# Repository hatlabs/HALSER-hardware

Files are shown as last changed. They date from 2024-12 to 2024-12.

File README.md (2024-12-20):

# Hat Labs Serial Interface Device (HALSER)

This repository contains the Hat Labs Serial Interface Device (HALSER) hardware design. HALSER is a powerful microcontroller development board designed for marine environments that allows interfacing with legacy NMEA 0183, RS-232 and UART devices.

Since the board has native WiFi and NMEA 2000 compatible CAN bus connectivity, it can be used to create boards with either Signal K or native NMEA 2000 connectivity (or both!).

## Features

The main design features include:

- Built around ESP32-C3, a powerful 32-bit microcontroller with 4 MB of flash
- Wide-range 5-32 V power input with surge protection
- NMEA 2000 compatible CAN interface (4-pin pluggable terminal block screw connector)
- One transmitting and one receiving RS-485 interface for bidirectional communication with NMEA 0183 devices (3-pin pluggable terminal block screw connectors)
- One RS-232 interface for communication with legacy devices (3-pin pluggable terminal block screw connector)
- One UART interface for general-purpose communication (3-pin pluggable terminal block screw connector). UART is 5V tolerant and the output voltage can be set to 3.3V or 5V with a jumper.
- 1-Wire interface (3-pin 2.54 mm header)
- I2C interface with a 4-pin 2.54 mm header
- USB type C interface for programming and serial communication
- All above interfaces with proper electromagnetic compatibilty (EMC) design -- the device won't interfere with navigational devices or radio equipment
- All available general-purpose input/output (GPIO) pins broken out to a separate header
- Board designed to fit low-cost waterproof 100x68x50 mm enclosures

Rendering of a version 1.0.0 board:

<!--
Front side.
![Rev. 1.0.0 board](images/pcb_rev_2.0.0.jpg)

Back side.
![Rev. 1.0.0 board bottom side](images/pcb_rev_2.0.0-back.jpg)

-->

## Getting HALSER

HALSER will be available for purchase at the [Hat Labs web store](https://shop.hatlabs.fi/).

## Documentation

HALSER documentation will be available at the [project GitHub Pages](https://docs.hatlabs.fi/halser/).

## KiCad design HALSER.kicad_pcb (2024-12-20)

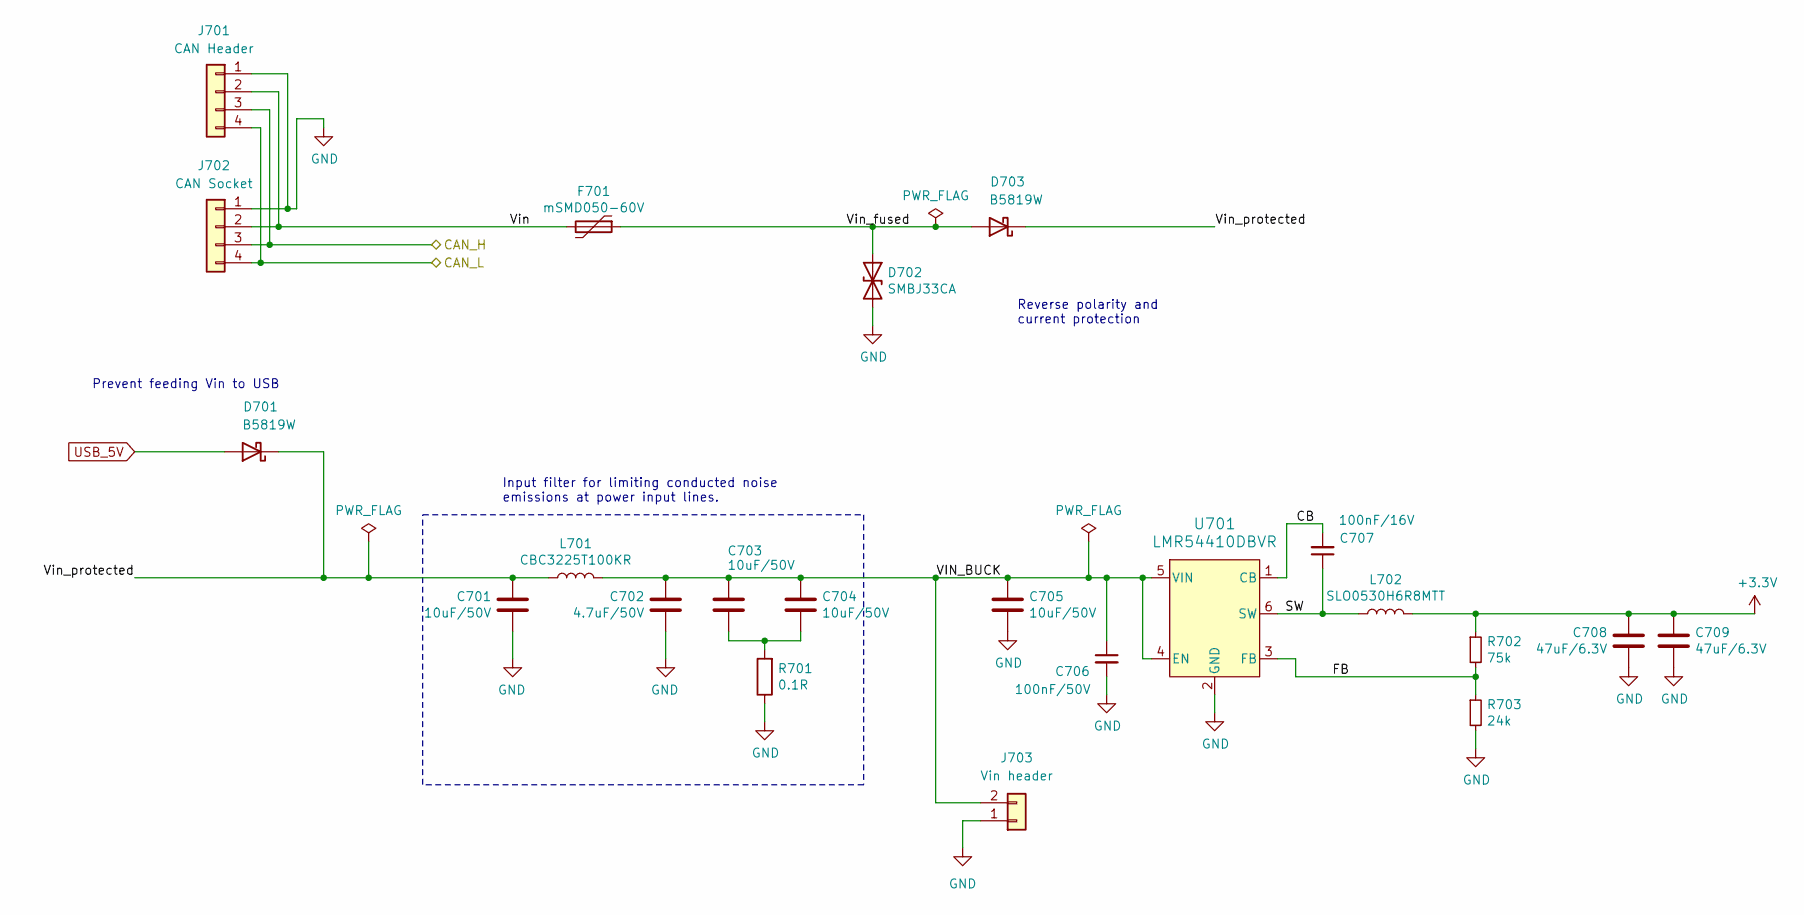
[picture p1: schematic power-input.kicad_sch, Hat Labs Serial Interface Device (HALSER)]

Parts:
C701, C703, C704, C705: 10uF/50V; C_1206_3216Metric; LCSC C13585
C702: 4.7uF/50V; C_0805_2012Metric; LCSC C1710
C706: 100nF/50V; C_0603_1608Metric; LCSC C14663
C707: 100nF/16V; C_0402_1005Metric; LCSC C1525
C708, C709: 47uF/6.3V; C_0805_2012Metric; LCSC C16780
D701, D703: B5819W; D_SOD-123; LCSC C8598
D702: SMBJ33CA; D_SMB; LCSC C114000
F701: mSMD050-60V; Fuse_1812_4532Metric; LCSC C70113
J701: CAN Header; PinHeader_1x04_P2.54mm_Vertical; LCSC C7430360
J702: CAN Socket; PhoenixContact_MCV_1,5_4-G-3.81_1x04_P3.81mm_Vertical; LCSC C8410
J703: Vin header; PinHeader_1x02_P2.54mm_Vertical; LCSC C492401
L701: CBC3225T100KR; L_1210_3225Metric; LCSC C90321
L702: SLO0530H6R8MTT; L_Chilisin_BMRA00050530; LCSC C325965
R701: 0.1R; R_0603_1608Metric; LCSC C3013345
R702: 75k; R_0402_1005Metric; LCSC C208939
R703: 24k; R_0402_1005Metric; LCSC C25769
U701: LMR54410DBVR; SOT-23-6; LCSC C3200265

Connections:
+3.3V: C708.1, C709.1, L702.2, R702.1; also elsewhere on the board
/CAN_H: J701.3, J702.3; also elsewhere on the board
/CAN_L: J701.4, J702.4; also elsewhere on the board
/Power input/CB: C707.2, U701.1 (CB)
/Power input/FB: R702.2, R703.1, U701.3 (FB)
/Power input/SW: C707.1, L702.1, U701.6 (SW)
/Power input/VIN_BUCK: C702.2, C703.1, C704.1, C705.1, C706.1, J703.2, L701.2, U701.4 (EN), U701.5 (VIN)
/Power input/Vin: F701.2, J701.2, J702.2
/Power input/Vin_fused: D702.1 (A1), D703.2 (A), F701.1
/Power input/Vin_protected: C701.1, D701.1 (K), D703.1 (K), L701.1
GND: C701.2, C702.1, C705.2, C706.2, C708.2, C709.2, D702.2 (A2), J701.1, J702.1, J703.1, R701.1, R703.2, U701.2 (GND); also elsewhere on the board
unnamed: C703.2, C704.2, R701.2
USB_5V: D701.2 (A); also elsewhere on the board

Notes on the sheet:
Input filter for limiting conducted noise emissions at power input lines.
Prevent feeding Vin to USB
Reverse polarity and current protection

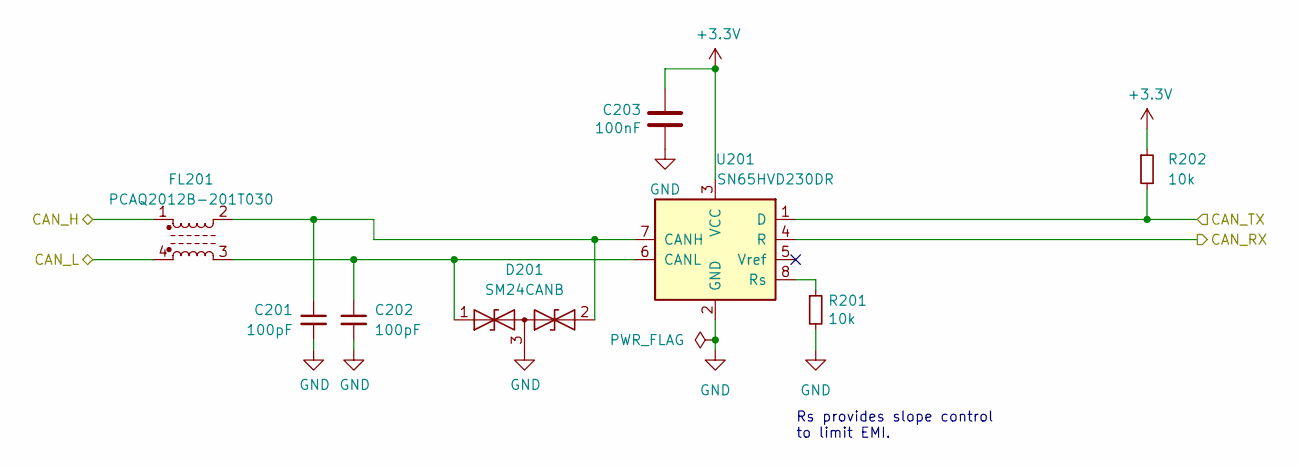
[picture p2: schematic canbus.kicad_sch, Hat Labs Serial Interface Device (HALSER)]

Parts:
C201, C202: 100pF; C_0603_1608Metric; LCSC C14858
C203: 100nF; C_0402_1005Metric; LCSC C1525
D201: SM24CANB; SOT-23; LCSC C19185908
FL201: PCAQ2012B-201T030; L_CommonModeChoke_PCAQ2012B; LCSC C2926967
R201, R202: 10k; R_0402_1005Metric; LCSC C25744
U201: SN65HVD230DR; SOIC-8_3.9x4.9mm_P1.27mm; LCSC C12084

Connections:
+3.3V: C203.1, R202.1, U201.3 (VCC); also elsewhere on the board
/CAN_H: FL201.1; also elsewhere on the board
/CAN_L: FL201.4; also elsewhere on the board
/CAN_RX: U201.4 (R); also elsewhere on the board
/CAN_TX: R202.2, U201.1 (D); also elsewhere on the board
GND: C201.2, C202.2, C203.2, D201.3 (common), R201.2, U201.2 (GND); also elsewhere on the board
unnamed: C202.1, D201.1 (A1), FL201.3, U201.6 (CANL)
unnamed: C201.1, D201.2 (A2), FL201.2, U201.7 (CANH)
unnamed: R201.1, U201.8 (Rs)

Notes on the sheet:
Rs provides slope control to limit EMI.

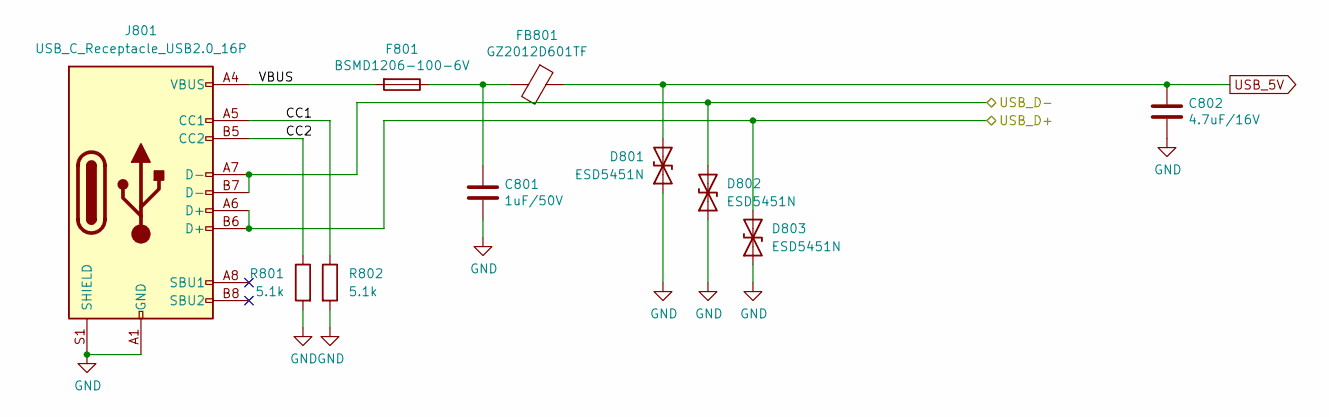
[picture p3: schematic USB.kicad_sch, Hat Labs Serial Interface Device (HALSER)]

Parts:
C801: 1uF/50V; C_0603_1608Metric; LCSC C15849
C802: 4.7uF/16V; C_0603_1608Metric; LCSC C19666
D801, D802, D803: ESD5451N; D_0402_1005Metric; LCSC C2936977
F801: BSMD1206-100-6V; Fuse_1206_3216Metric; LCSC C883129
FB801: GZ2012D601TF; L_0805_2012Metric; LCSC C1017
J801: USB_C_Receptacle_USB2.0_16P; Shou Han Type-C 16P LTH6.8; LCSC C5187468
R801, R802: 5.1k; R_0402_1005Metric; LCSC C25905

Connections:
/USB/CC1: J801.A5 (CC1), R802.1
/USB/CC2: J801.B5 (CC2), R801.1
/USB/VBUS: F801.2, J801.A4 (VBUS), J801.A9 (VBUS), J801.B4 (VBUS), J801.B9 (VBUS)
/USB_D+: D803.2 (A2), J801.A6 (D+), J801.B6 (D+); also elsewhere on the board
/USB_D-: D802.2 (A2), J801.A7 (D-), J801.B7 (D-); also elsewhere on the board
GND: C801.2, C802.2, D801.1 (A1), D802.1 (A1), D803.1 (A1), J801.A1 (GND), J801.A12 (GND), J801.B1 (GND), J801.B12 (GND), J801.S1 (SHIELD), R801.2, R802.2; also elsewhere on the board
unnamed: C801.1, F801.1, FB801.2
USB_5V: C802.1, D801.2 (A2), FB801.1; also elsewhere on the board

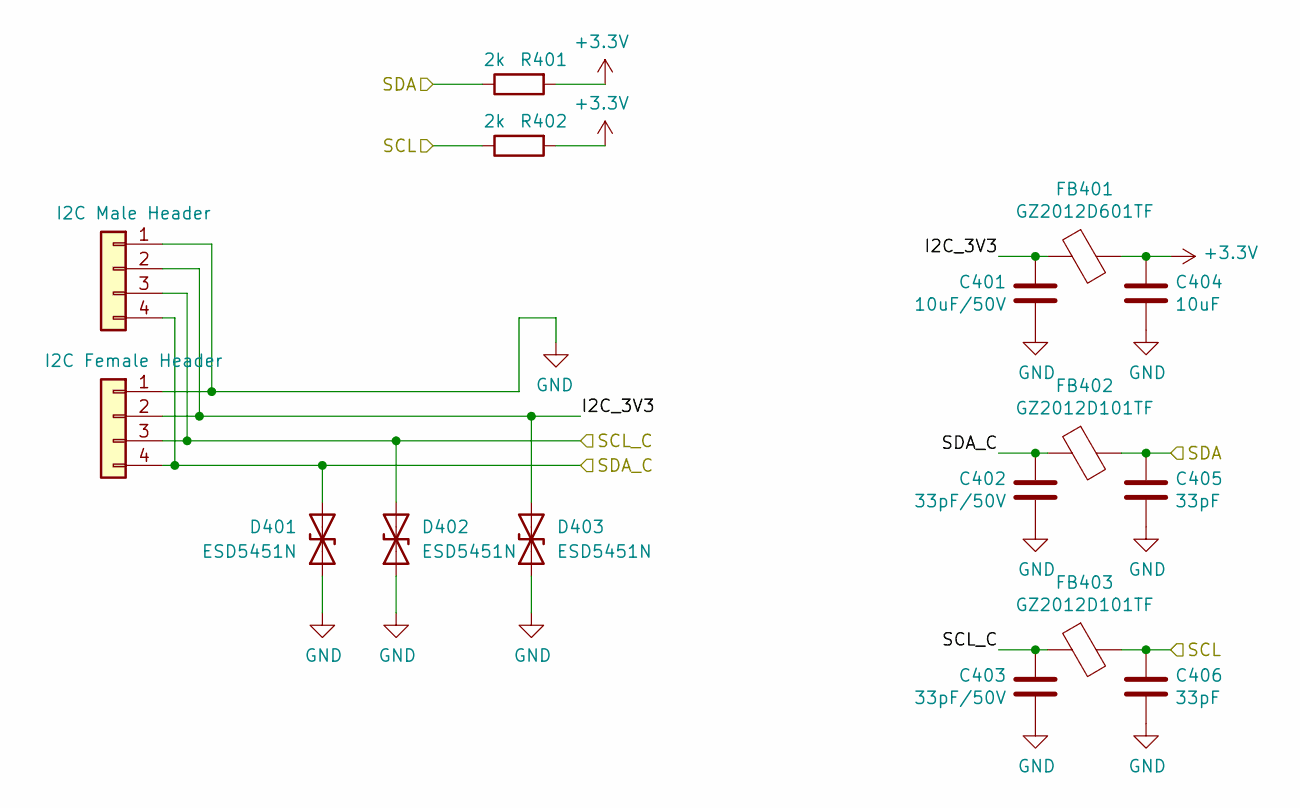
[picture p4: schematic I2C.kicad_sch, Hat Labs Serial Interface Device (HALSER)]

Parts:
C401: 10uF/50V; C_1206_3216Metric; LCSC C13585
C402, C403: 33pF/50V; C_0603_1608Metric; LCSC C1663
C404: 10uF; C_0603_1608Metric; LCSC C19702
C405, C406: 33pF; C_0402_1005Metric; LCSC C1562
D401, D402, D403: ESD5451N; D_0402_1005Metric; LCSC C2936977
FB401: GZ2012D601TF; L_0805_2012Metric; LCSC C1017
FB402, FB403: GZ2012D101TF; L_0805_2012Metric; LCSC C1015
J401: I2C Male Header; PinHeader_1x04_P2.54mm_Vertical; LCSC C6332197
J402: I2C Female Header; PinSocket_1x04_P2.54mm_Vertical; LCSC C2718488
R401, R402: 2k; R_0402_1005Metric; LCSC C4109

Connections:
+3.3V: C404.1, FB401.2, R401.2, R402.2; also elsewhere on the board
/I2C/I2C_3V3: C401.1, D403.2 (A2), FB401.1, J401.2, J402.2
/SCL: C406.1, FB403.2, R402.1; also elsewhere on the board
/SCL_C: C403.1, D402.2 (A2), FB403.1, J401.3, J402.3; also elsewhere on the board
/SDA: C405.1, FB402.2, R401.1; also elsewhere on the board
/SDA_C: C402.1, D401.2 (A2), FB402.1, J401.4, J402.4; also elsewhere on the board
GND: C401.2, C402.2, C403.2, C404.2, C405.2, C406.2, D401.1 (A1), D402.1 (A1), D403.1 (A1), J401.1, J402.1; also elsewhere on the board

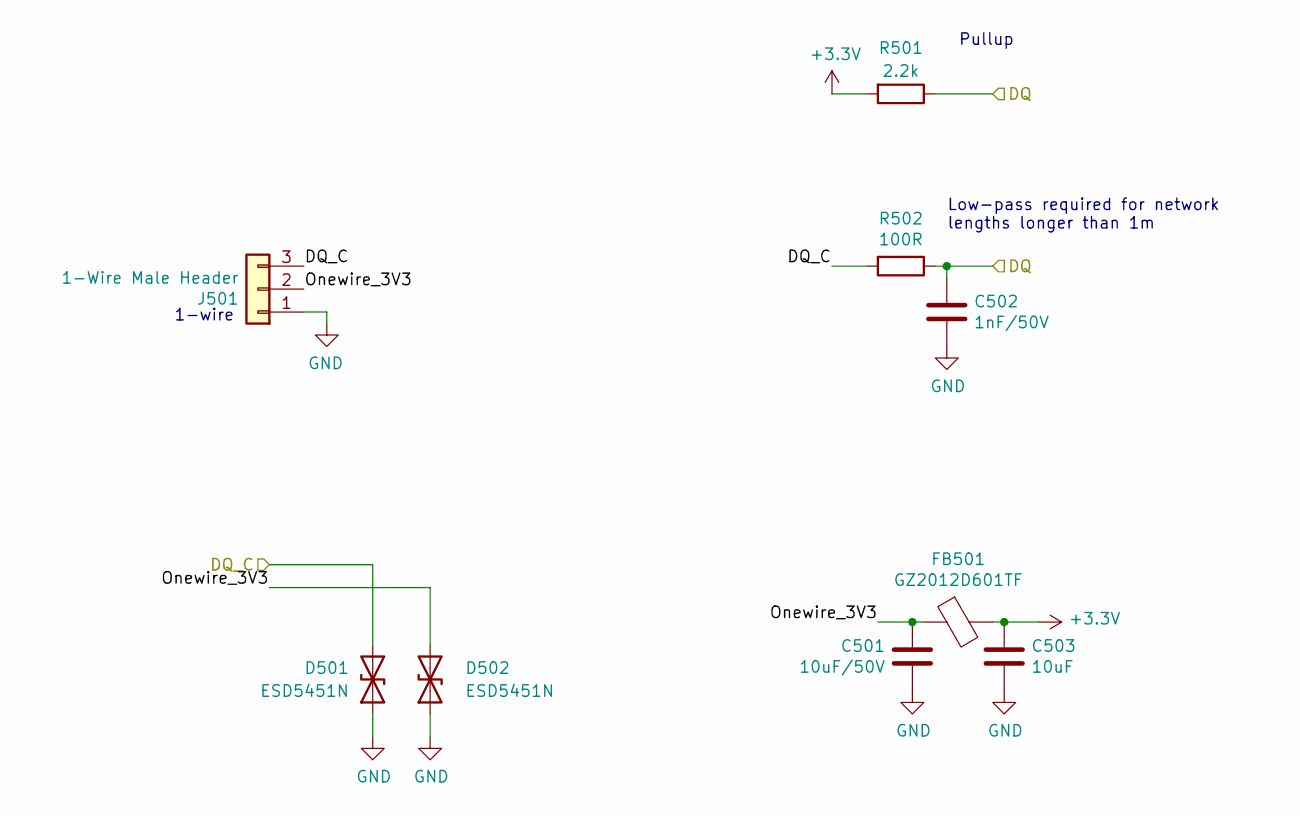
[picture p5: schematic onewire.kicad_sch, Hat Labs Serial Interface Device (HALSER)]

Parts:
C501: 10uF/50V; C_1206_3216Metric; LCSC C13585
C502: 1nF/50V; C_0603_1608Metric; LCSC C1588
C503: 10uF; C_0603_1608Metric; LCSC C19702
D501, D502: ESD5451N; D_0402_1005Metric; LCSC C2936977
FB501: GZ2012D601TF; L_0805_2012Metric; LCSC C1017
J501: 1-Wire Male Header; PinHeader_1x03_P2.54mm_Vertical; LCSC C49257
R501: 2.2k; R_0402_1005Metric; LCSC C25879
R502: 100R; R_0805_2012Metric; LCSC C17408

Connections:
+3.3V: C503.1, FB501.2, R501.2; also elsewhere on the board
/DQ: C502.1, R501.1, R502.1; also elsewhere on the board
/DQ_C: D501.2 (A2), J501.3, R502.2; also elsewhere on the board
/Onewire/Onewire_3V3: C501.1, D502.2 (A2), FB501.1, J501.2
GND: C501.2, C502.2, C503.2, D501.1 (A1), D502.1 (A1), J501.1; also elsewhere on the board

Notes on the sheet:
1-wire
Low-pass required for network lengths longer than 1m
Pullup

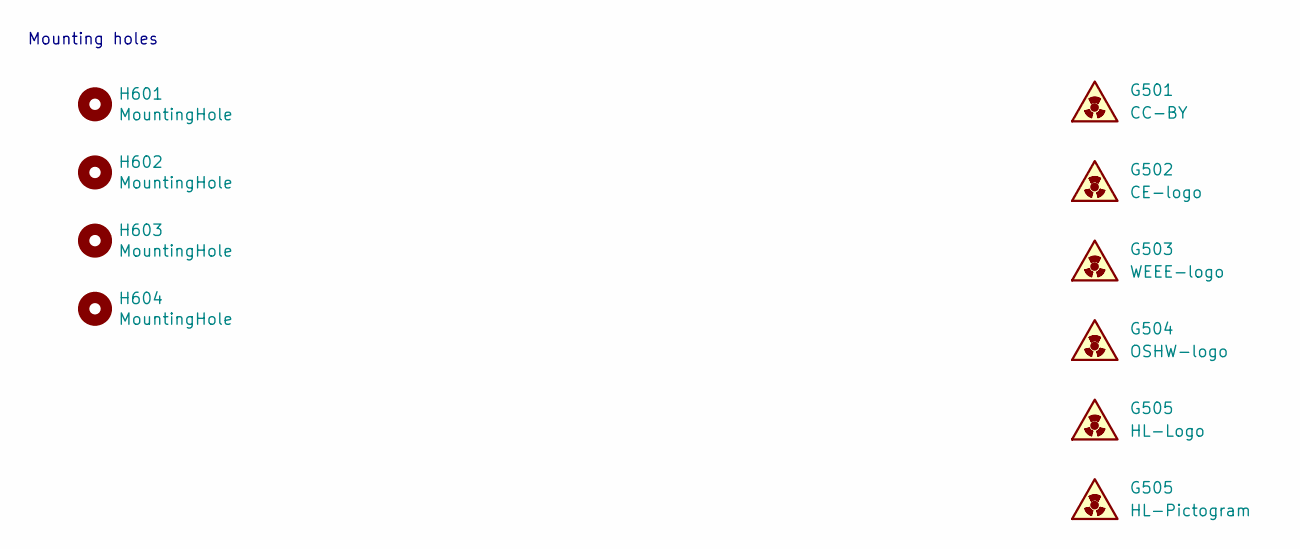
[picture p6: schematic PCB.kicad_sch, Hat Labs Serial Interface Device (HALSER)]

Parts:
G501: CC-BY; cc-by_5mm
G502: CE-logo; CE-Logo_11.2x8mm_SilkScreen
G503: WEEE-logo; WEEE-Logo_5.6x8mm_SilkScreen
G504: OSHW-logo; OSHW-Logo2_9.8x8mm_SilkScreen
G505: HL-Logo; Hat_Labs_25.4mm
H601, H602, H603, H604: MountingHole; MountingHole_3.2mm_M3_ISO7380

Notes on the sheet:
Mounting holes

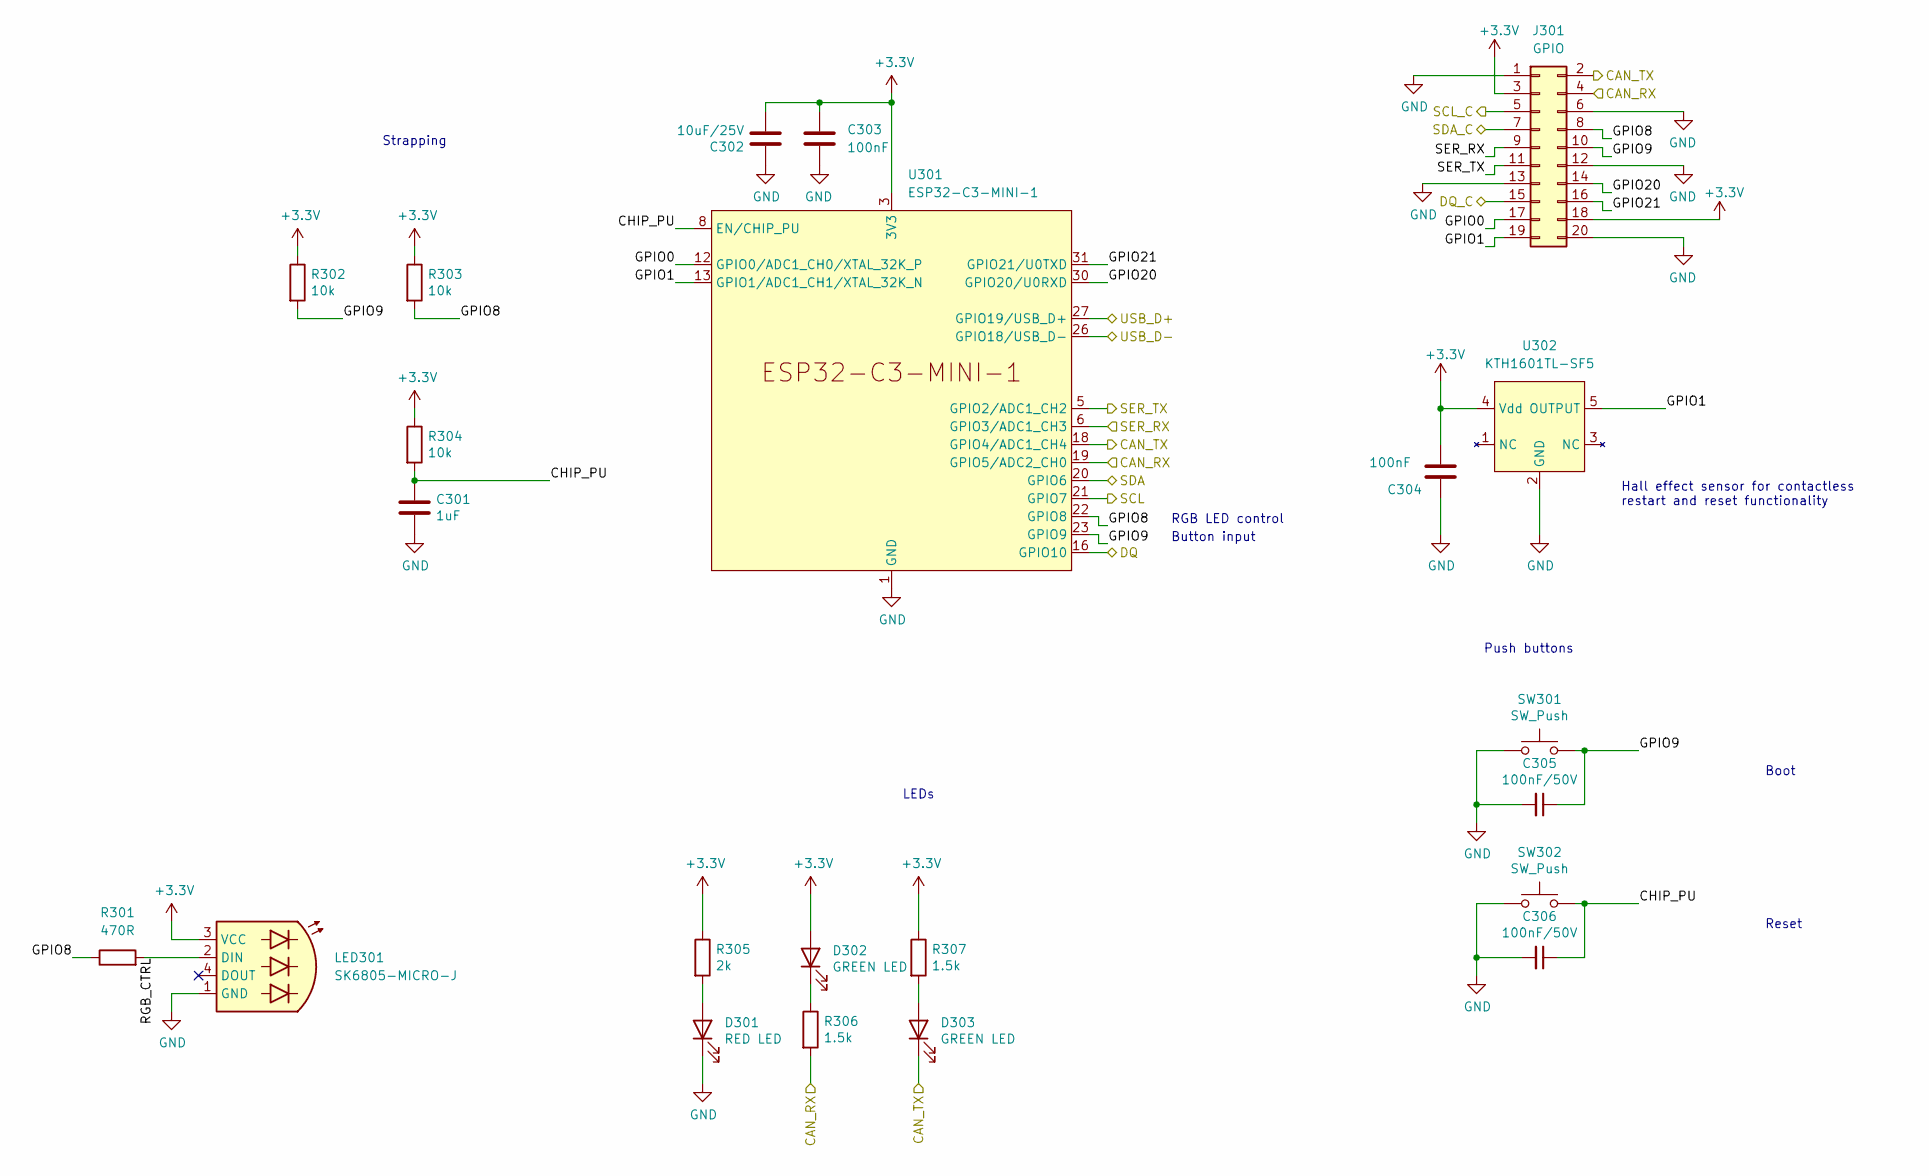
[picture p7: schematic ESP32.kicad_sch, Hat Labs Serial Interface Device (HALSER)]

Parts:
C301: 1uF; C_0402_1005Metric; LCSC C52923
C302: 10uF/25V; C_0805_2012Metric; LCSC C15850
C303, C304: 100nF; C_0402_1005Metric; LCSC C1525
C305, C306: 100nF/50V; C_0603_1608Metric; LCSC C14663
D301: RED LED; LED_0603_1608Metric; LCSC C2286
D302, D303: GREEN LED; LED_0603_1608Metric; LCSC C965804
J301: GPIO; PinHeader_2x10_P2.54mm_Vertical; LCSC C7501600
LED301: SK6805-MICRO-J; LED_SK6805_PLCC4_2.4x2.7mm_P1.3mm; LCSC C2909056
R301: 470R; R_0603_1608Metric
R302, R303, R304: 10k; R_0402_1005Metric; LCSC C25744
R305: 2k; R_0402_1005Metric; LCSC C4109
R306, R307: 1.5k; R_0402_1005Metric; LCSC C25867
SW301, SW302: SW_Push; SW_SPST_TL3342; LCSC C318887
U301: ESP32-C3-MINI-1; LCSC C2934569
U302: KTH1601TL-SF5; SOT-553; LCSC C962140

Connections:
+3.3V: C302.2, C303.1, C304.2, D302.2 (A), J301.3, J301.18, LED301.3 (VCC), R302.1, R303.1, R304.1, R305.1, R307.1, U301.3 (3V3), U302.4 (Vdd); also elsewhere on the board
/CAN_RX: J301.4, R306.2, U301.19 (GPIO5/ADC2_CH0); also elsewhere on the board
/CAN_TX: D303.1 (K), J301.2, U301.18 (GPIO4/ADC1_CH4); also elsewhere on the board
/DQ: U301.16 (GPIO10); also elsewhere on the board
/DQ_C: J301.15; also elsewhere on the board
/ESP32/CHIP_PU: C301.1, C306.1, R304.2, SW302.2, U301.8 (EN/CHIP_PU)
/ESP32/GPIO0: J301.17, U301.12 (GPIO0/ADC1_CH0/XTAL_32K_P)
/ESP32/GPIO1: J301.19, U301.13 (GPIO1/ADC1_CH1/XTAL_32K_N), U302.5 (OUTPUT)
/ESP32/GPIO8: J301.8, R301.1, R303.2, U301.22 (GPIO8)
/ESP32/GPIO9: C305.1, J301.10, R302.2, SW301.2, U301.23 (GPIO9)
/ESP32/GPIO20: J301.14, U301.30 (GPIO20/U0RXD)
/ESP32/GPIO21: J301.16, U301.31 (GPIO21/U0TXD)
/ESP32/RGB_CTRL: LED301.2 (DIN), R301.2
/SCL: U301.21 (GPIO7); also elsewhere on the board
/SCL_C: J301.7; also elsewhere on the board
/SDA: U301.20 (GPIO6); also elsewhere on the board
/SDA_C: J301.5; also elsewhere on the board
/SER_RX: J301.9, U301.6 (GPIO3/ADC1_CH3); also elsewhere on the board
/SER_TX: J301.11, U301.5 (GPIO2/ADC1_CH2); also elsewhere on the board
/USB_D+: U301.27 (GPIO19/USB_D+); also elsewhere on the board
/USB_D-: U301.26 (GPIO18/USB_D-); also elsewhere on the board
GND: C301.2, C302.1, C303.2, C304.1, C305.2, C306.2, D301.1 (K), J301.1, J301.6, J301.12, J301.13, J301.20, LED301.1 (GND), SW301.1, SW302.1, U301.1 (GND), U301.2 (GND), U301.11 (GND), U301.14 (GND), U301.36 (GND), U301.37 (GND), U301.38 (GND), U301.39 (GND), U301.40 (GND), U301.41 (GND), U301.42 (GND), U301.43 (GND), U301.44 (GND), U301.45 (GND), U301.46 (GND), U301.47 (GND), U301.48 (GND), U301.49 (GND), U301.50 (GND), U301.51 (GND), U301.52 (GND), U301.53 (GND), U302.2 (GND); also elsewhere on the board
unnamed: D301.2 (A), R305.2
unnamed: D302.1 (K), R306.1
unnamed: D303.2 (A), R307.2

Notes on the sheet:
Hall effect sensor for contactless restart and reset functionality
Button input
Strapping
RGB LED control
Reset
Boot
LEDs
Push buttons

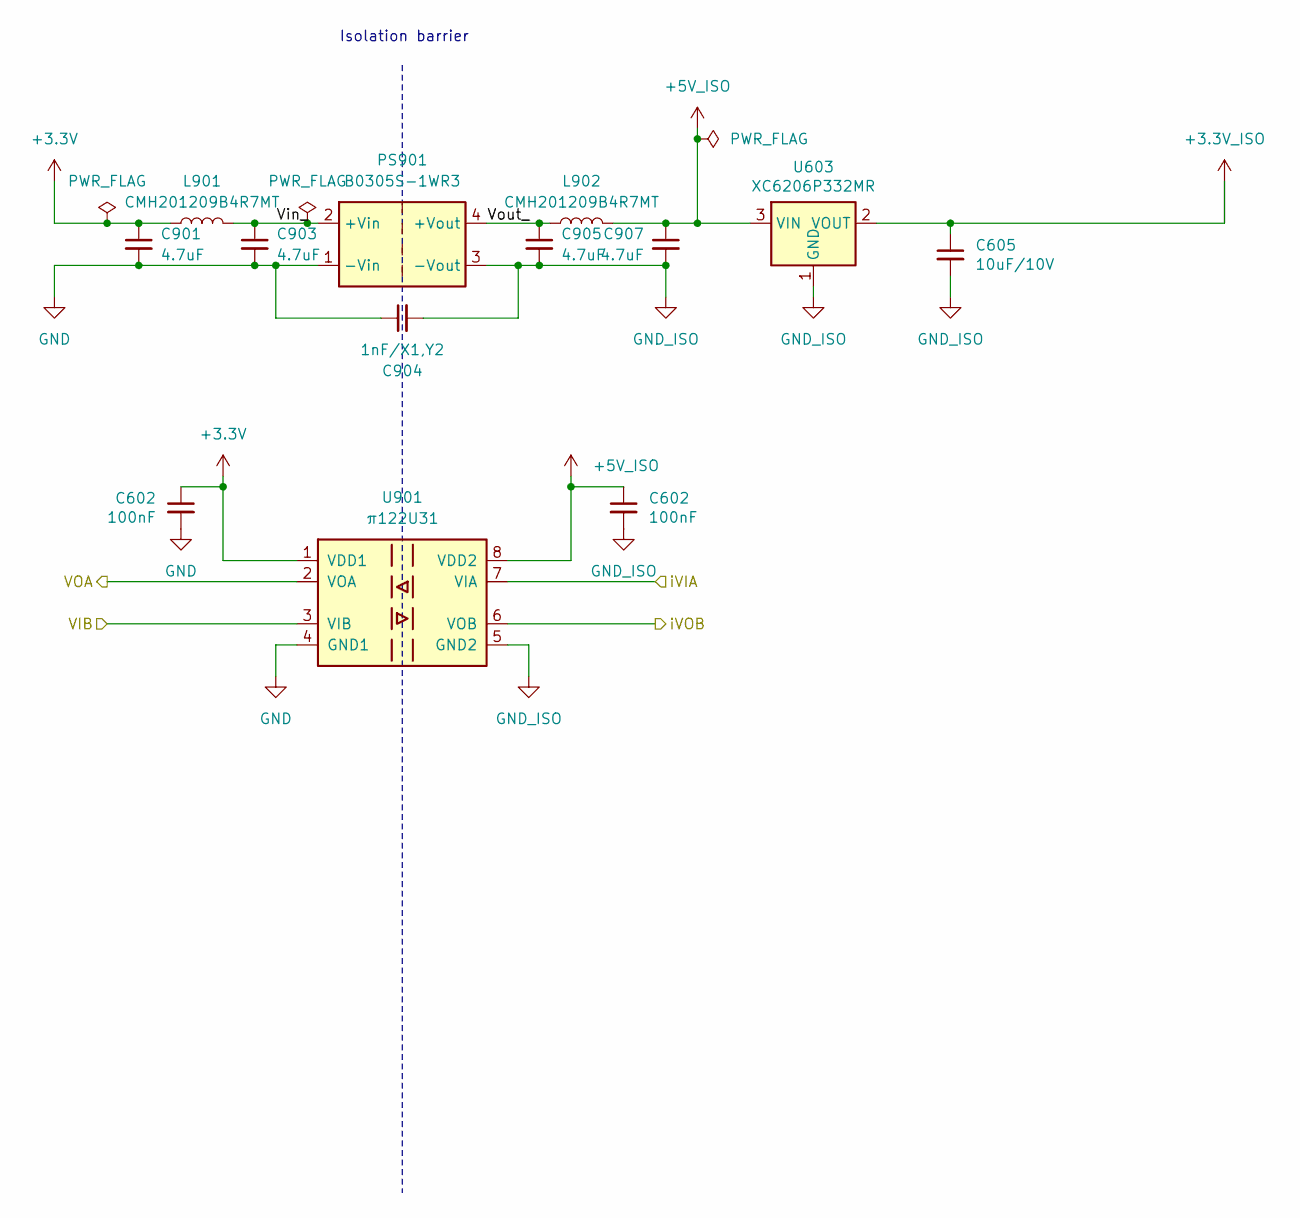
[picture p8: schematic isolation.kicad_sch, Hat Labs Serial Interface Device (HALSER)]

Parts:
C602: 100nF; C_0402_1005Metric; LCSC C1525
C605: 10uF/10V; C_0603_1608Metric; LCSC C19702
C901, C903, C905, C907: 4.7uF; C_0603_1608Metric; LCSC C19666
C904: 1nF/X1,Y2; C_1808_4520Metric; LCSC C784081
L901, L902: CMH201209B4R7MT; L_0805_2012Metric; LCSC C394959
PS901: B0305S-1WR3; Converter_DCDC_Murata_MEE1SxxxxSC_THT; LCSC C7465186
U603: XC6206P332MR; SOT-23; LCSC C5446
U901: π122U31; SOIC-8_3.9x4.9mm_P1.27mm; LCSC C471590

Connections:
+3.3V: C901.1, L901.1, U901.1 (VDD1); also elsewhere on the board
+5V_ISO: C907.1, L902.2, U901.8 (VDD2); also elsewhere on the board
/Isolation barrier/Vin_: C903.1, L901.2, PS901.2 (+Vin)
/Isolation barrier/Vout_: C905.1, L902.1, PS901.4 (+Vout)
/Isolation barrier/iVIA: U901.7 (VIA); also elsewhere on the board
/Isolation barrier/iVOB: U901.6 (VOB); also elsewhere on the board
/SER_RX: U901.2 (VOA); also elsewhere on the board
/SER_TX: U901.3 (VIB); also elsewhere on the board
GND: C901.2, C903.2, C904.1, PS901.1 (-Vin), U901.4 (GND1); also elsewhere on the board
GND_ISO: C904.2, C905.2, C907.2, PS901.3 (-Vout), U901.5 (GND2); also elsewhere on the board

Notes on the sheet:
Isolation barrier

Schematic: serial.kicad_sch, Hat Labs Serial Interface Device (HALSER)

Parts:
C1001, C1002, C1003, C1004, C1005, C1006, C1007, C1008: 100nF; C_0402_1005Metric; LCSC C1525
C1009, C1010, C1011, C1012, C1015, C1016, C1017, C1018: 100pF; C_0603_1608Metric; LCSC C14858
C1013, C1014, C1019, C1020: 150pF/50V; C_0603_1608Metric; LCSC C1594
D1001, D1002: GREEN LED; LED_0603_1608Metric; LCSC C965804
D1003, D1004: SM712_SOT23; SOT-23; LCSC C521963
D1005: PESD15VS2UT; SOT-23; LCSC C2831524
D1006, D1009: ESD5451N; D_0402_1005Metric; LCSC C2936977
D1007, D1008: SMAJ16CA; D_SMA; LCSC C5356049
F1001, F1002, F1003, F1004: nSMD005/60V; Fuse_1206_3216Metric; LCSC C2830235
FB1001, FB1002, FB1003, FB1004: GZ2012D601TF; L_0805_2012Metric; LCSC C1017
FL1001, FL1002: PCAQ2012B-201T030; L_CommonModeChoke_PCAQ2012B; LCSC C2926967
J1001: RX Sel Header; PinHeader_2x03_P2.54mm_Vertical; LCSC C5383104
J1002: RS485 RX Socket; PhoenixContact_MCV_1,5_3-G-3.81_1x03_P3.81mm_Vertical; LCSC C8389
J1003: RS485 TX Socket; PhoenixContact_MCV_1,5_3-G-3.81_1x03_P3.81mm_Vertical; LCSC C8389
J1004: RS-232 Socket; PhoenixContact_MCV_1,5_3-G-3.81_1x03_P3.81mm_Vertical; LCSC C8389
J1005: UART Socket; PhoenixContact_MCV_1,5_3-G-3.81_1x03_P3.81mm_Vertical; LCSC C8389
JP1001: UART V-sel; PinHeader_1x03_P2.54mm_Vertical
R1001, R1002: 2.2k; R_0402_1005Metric
R1003, R1004, R1005, R1006: 10R; R_0402_1005Metric; LCSC C25077
R1007, R1008: 51R; R_0603_1608Metric; LCSC C23197
R1009, R1010: 470R; R_0603_1608Metric; LCSC C23179
U1001: 74LVC2G17; SOT-23-6; LCSC C10429
U1002, U1004: SN75176BDR; SOIC-8_3.9x4.9mm_P1.27mm; LCSC C2829048
U1003: SP3232EEY-L/TR; TSSOP-16_4.4x5mm_P0.65mm; LCSC C13482

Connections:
+3.3V_ISO: JP1001.1 (A); also elsewhere on the board
+5V_ISO: C1001.2, C1002.2, C1003.2, JP1001.3 (B), R1001.1, R1002.1, U1002.8 (VCC), U1003.8 (R2IN), U1003.10 (T2IN), U1003.16 (VCC), U1004.2 (~RE), U1004.3 (DE), U1004.8 (VCC); also elsewhere on the board
/Isolation barrier/iVIA: D1001.1 (K), J1001.1, J1001.3, J1001.5; also elsewhere on the board
/Isolation barrier/iVOB: D1002.1 (K), U1001.1, U1003.11 (T1IN), U1004.4 (D); also elsewhere on the board
/Serial interfaces/RS232_RX: J1001.4, U1003.12 (R1OUT)
/Serial interfaces/RS232_RX_C: J1004.2, R1008.2
/Serial interfaces/RS232_RX_IN: C1014.1, FB1004.1, U1003.13 (R1IN)
/Serial interfaces/RS232_TX_C: J1004.3, R1007.2
/Serial interfaces/RS232_TX_OUT: C1013.1, FB1003.1, U1003.14 (T1OUT)
/Serial interfaces/RS485_RX: J1001.6, U1002.1 (R)
/Serial interfaces/RS485_RX_A: R1004.1, U1002.6 (A)
/Serial interfaces/RS485_RX_A_C: F1002.1, J1002.2
/Serial interfaces/RS485_RX_B: R1003.1, U1002.7 (B)
/Serial interfaces/RS485_RX_B_C: F1001.1, J1002.3
/Serial interfaces/RS485_TX_A: R1006.1, U1004.6 (A)
/Serial interfaces/RS485_TX_A_C: F1003.1, J1003.3
/Serial interfaces/RS485_TX_B: R1005.1, U1004.7 (B)
/Serial interfaces/RS485_TX_B_C: F1004.1, J1003.2
/Serial interfaces/UART_RX: J1001.2, U1001.4
/Serial interfaces/UART_RX_C: J1005.2, R1010.2
/Serial interfaces/UART_RX_IN: C1012.1, FB1002.1, U1001.3
/Serial interfaces/UART_TX_C: J1005.3, R1009.2
/Serial interfaces/UART_TX_OUT: C1011.1, FB1001.1, U1001.6
/Serial interfaces/Vsel: C1005.1, JP1001.2 (C), U1001.5 (VCC)
GND_ISO: C1001.1, C1002.1, C1003.1, C1005.2, C1007.2, C1008.1, C1009.2, C1010.2, C1011.2, C1012.2, C1013.2, C1014.2, C1015.2, C1016.2, C1017.2, C1018.2, C1019.2, C1020.2, D1003.3 (common), D1004.3 (common), D1005.3 (common), D1006.1 (A1), D1009.1 (A1), J1002.1, J1003.1, J1004.1, J1005.1, U1001.2 (GND), U1002.2 (~RE), U1002.3 (DE), U1002.4 (D), U1002.5 (GND), U1003.15 (GND), U1004.5 (GND); also elsewhere on the board
unnamed: C1009.1, FL1001.1, R1003.2
unnamed: C1010.1, FL1002.1, R1005.2
unnamed: C1015.1, FL1001.4, R1004.2
unnamed: C1016.1, FL1002.4, R1006.2
unnamed: D1001.2 (A), R1001.2
unnamed: D1002.2 (A), R1002.2
unnamed: D1003.1 (A1), D1007.2 (A2), F1001.2, FL1001.2
unnamed: D1003.2 (A2), D1007.1 (A1), F1002.2, FL1001.3
unnamed: D1004.1 (A1), D1008.2 (A2), F1003.2, FL1002.2
unnamed: D1004.2 (A2), D1008.1 (A1), F1004.2, FL1002.3
unnamed: C1019.1, D1005.1 (A1), FB1003.2, R1007.1
unnamed: C1020.1, D1005.2 (A2), FB1004.2, R1008.1
unnamed: C1017.1, D1006.2 (A2), FB1001.2, R1009.1
unnamed: C1018.1, D1009.2 (A2), FB1002.2, R1010.1
unnamed: C1004.1, U1003.1 (C1+)
unnamed: C1004.2, U1003.3 (C1-)
unnamed: C1006.1, U1003.4 (C2+)
unnamed: C1006.2, U1003.5 (C2-)
unnamed: C1008.2, U1003.2 (VS+)
unnamed: C1007.1, U1003.6 (VS-)

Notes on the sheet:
RS-485 TX
UART
RS-232
RX selection
RS-485 RX

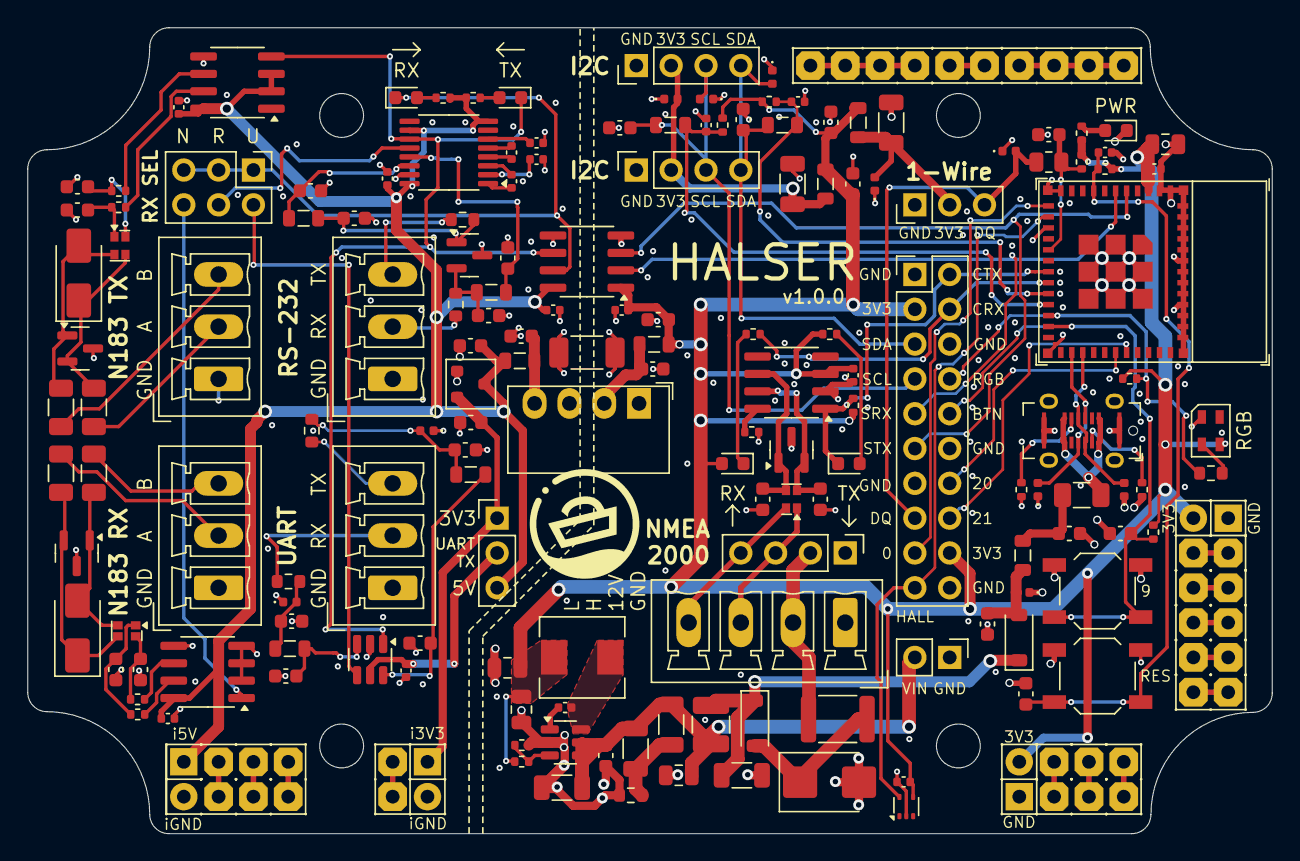
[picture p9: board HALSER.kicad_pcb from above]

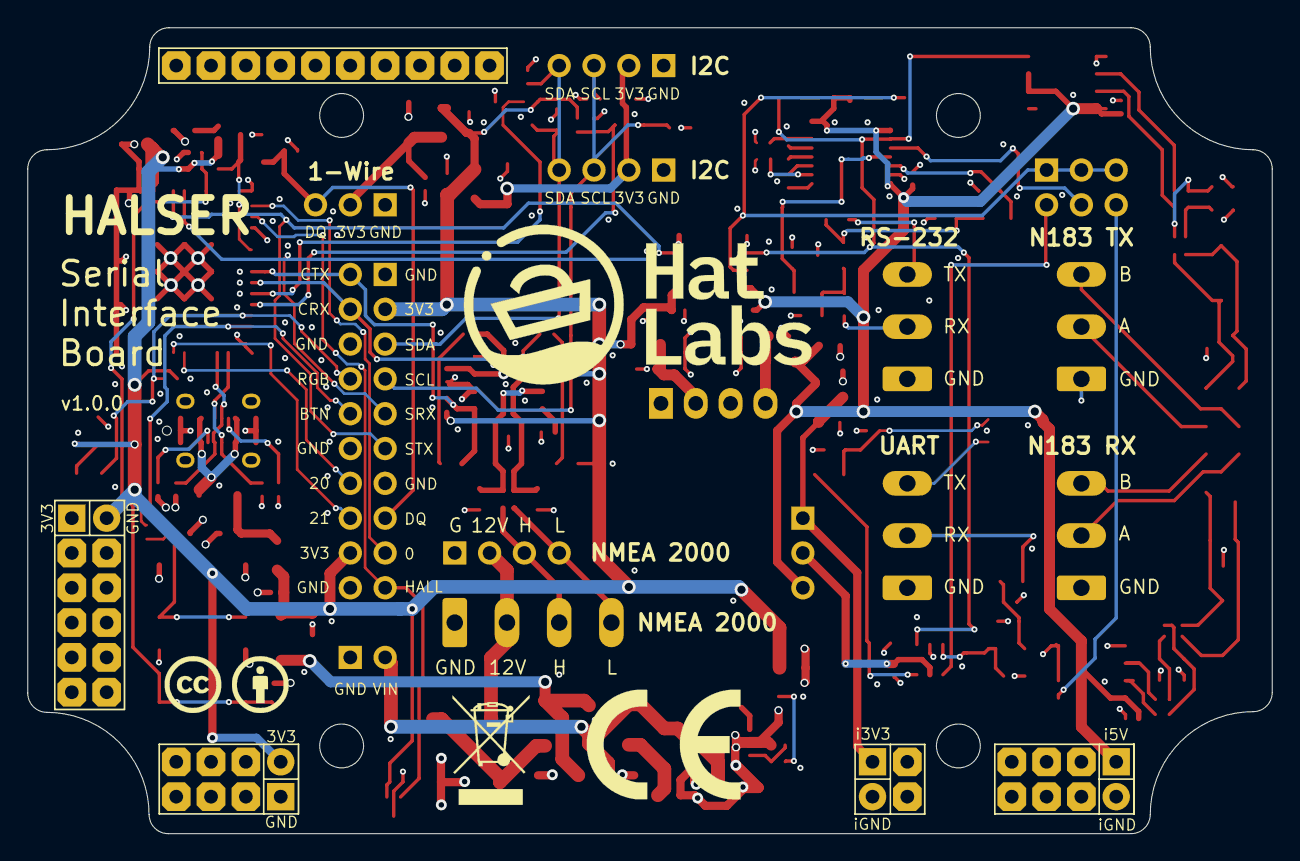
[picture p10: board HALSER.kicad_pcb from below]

Board: 4 copper layers, 90.8 x 58.8 mm, 168 parts (4 on the bottom side), 92 nets.

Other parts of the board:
C902, C906: 100nF; C_0402_1005Metric
C908: 10uF/10V; C_0603_1608Metric
G601: CC-BY; cc-by_5mm
G602: CE-logo; CE-Logo_11.2x8mm_SilkScreen
G603: WEEE-logo; WEEE-Logo_5.6x8mm_SilkScreen
G605: HL-Logo; Hat_Labs_25.4mm
G606: HL-Pictogram; HaL_picto_8mm
U902: XC6206P332MR; SOT-23

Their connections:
+3.3V: C902.1; also elsewhere on the board
+3.3V_ISO: C908.1, U902.2 (VOUT); also elsewhere on the board
+5V_ISO: C906.1, U902.3 (VIN); also elsewhere on the board
GND: C902.2; also elsewhere on the board
GND_ISO: C906.2, C908.2, U902.1 (GND); also elsewhere on the board

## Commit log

2024-10-20 Rename HALMET -> HALSER
    [HALSER.kicad_pcb, HALSER.kicad_sch]
2024-10-22 Redo schematics
    [ESP32.kicad_sch, HALSER.kicad_sch, I2C.kicad_sch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]
2024-10-24 WIP wiring
    [ESP32.kicad_sch, HALSER.kicad_pcb, I2C.kicad_sch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]
2024-10-27 Further design adjustments
    [ESP32.kicad_sch, HALSER.kicad_pcb, HALSER.kicad_sch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]
2024-10-28 Further manufacturing tweaks
    [ESP32.kicad_sch, HALSER.kicad_pcb, I2C.kicad_sch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]
2024-10-28 Update assembly scripts
2024-10-28 FIXUP vias
    [HALSER.kicad_pcb]
2024-11-20 Add a hall effect sensor
    [ESP32.kicad_sch]
2024-12-12 Fix issues found in -a1
    [ESP32.kicad_sch, HALSER.kicad_pcb, HALSER.kicad_sch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]
2024-12-20 Bump versions
    [ESP32.kicad_sch, HALSER.kicad_pcb, HALSER.kicad_sch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]

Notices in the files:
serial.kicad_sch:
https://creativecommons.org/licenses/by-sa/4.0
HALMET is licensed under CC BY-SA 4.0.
